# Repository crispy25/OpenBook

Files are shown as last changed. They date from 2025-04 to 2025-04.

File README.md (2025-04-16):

# OpenBook - TSC Project
### Author: Popescu Cristian-Emanuel 332CA

## Diagram

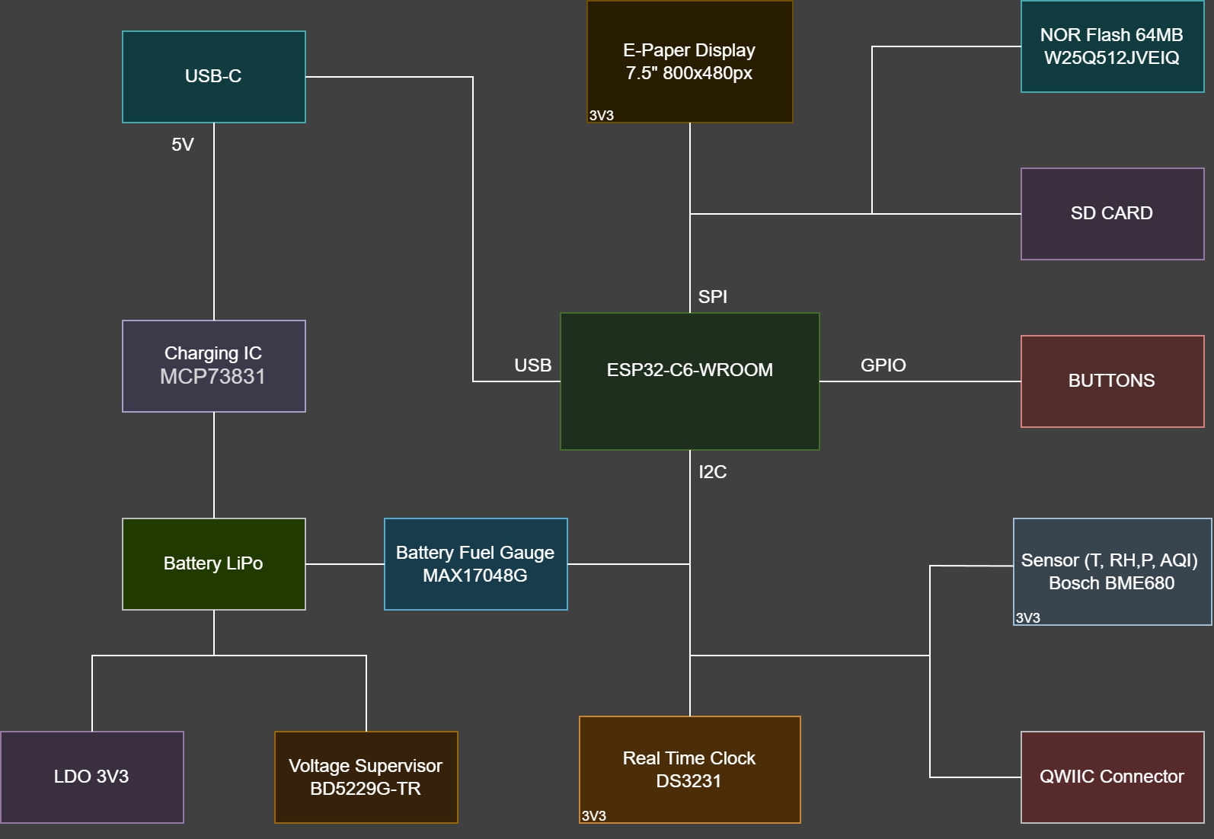
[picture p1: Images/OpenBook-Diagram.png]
OpenBook Diagram


## Hardware functionality

+ ESP32-C6 MCU
    - Manages all peripherals, including the display, sensors, buttons, and USB-C interface.
    - Interfaces: SPI, I2C, USB, UART, Wi-Fi

+ Power Supply - CELLEVIA BATTERIES LP584174
    - The 1800mAh Polymer Lithium-Ion battery is connected to the charging IC.
    - A single LDO generates the required single 3.3V power rail for the entire board, powering the ESP32, sensors and other components.

+ Battery management - MAX17048G+T10
    - The battery management module is using the I2C interface to communicate with the battery fuel gauge IC.
    - The charging IC is controlled via GPIO pins.

+ Display Interface - Waveshare WSH-13187 7.5" e-Paper display 
    - The 800x480 resolution display is connected to the ESP32-C6 via a 4-wire SPI interface.
    - Dedicated CS, DC, RST, and BUSY pins are used for control.

+ Sensor - Bosch BME680
    - Measures temperature, humidity, pressure and air quality.
    - The BME680 sensor is connected to the ESP32-C6 via an I2C bus.
    - Pull-up resistors are used on the I2C lines.

+ RTC - DS3231
    - Real Time Clock with supercapacitor back-up.
    - Connected via I2C interface.

+ User Interface
    - The three tactile buttons are connected to GPIO pins on the ESP32-C6.
    - Hardware debouncing circuitry is implemented using RC filters.
    - The RESET button restarts the device, typically used to recover from unresponsive states or system errors.
    - The BOOT button allows the user to start up the device.
    - The CHANGE button lets the user scroll or cycle through menus and book selections.

+ External NOR Flash 64MB - W25Q512JVEIQ
    - Non-Volatile flash memory that provides a storage solution.
    - Interface: SPI

+ USB-C Interface
    - The USB-C connector is connected to the ESP32-C6's USB interface.
    - A dedicated ESD protection IC is used on the data and power lines.
    - Proper termination resistors are used for USB-C implementation.

+ SD Memory Card Connector - Attend Tech 112A-TAAR-R03
    - Interface: SPI

+ Qwiic / Stemma QT
    - Plug-and-play I2C connection system for easy expansion of peripheral modules.

## Power management and consumption

| Mode | ESP32  | EPD  | BME680 | DS3231  | MAX17048 | SD Card | Total Current | Runtime |
|---|---|---|---|---|---|---|---|:---:|
| Active | 100mA  | 30mA | 2mA | 0.2mA | 0.05mA | 80mA | ~212 mA | ~8.5 hours |
| Idle | 50mA | 1µA  | 150µA | 0.2mA | 0.05mA | 2mA | ~52.4 mA | ~1.4 days |
| Deep Sleep | 0.15mA | 1µA  | 0.00015mA | 0.003mA | 0.001mA  | 0.1mA | ~0.255 mA | ~9.7 months |

## ESP32-C6 Pin description

+ EN -> Resets the MCU
+ IO0 - INT_RTC -> Used to receive interrupts signals from RTC, allowing for two major functionalities: Alarm and Square Wave Output
+ IO1 - 32KHz -> Used for a stable clock signal of 32.768 kHz generated by the RTC
+ IO2 – MISO -> Master In Slave Out Signal, used in the SPI communication with the SD Card
+ IO3 - EPD_BUSY -> Indicates display driver status
+ IO4 – SS_SD -> Chip select for SPI communication with SD Card
+ IO5 – EPD_DC -> Display serial communication Command/Data input
+ IO6 – SCK -> Clock signal for I2C communication
+ IO7 – MOSI -> Master Out Slave In Signal, used to send data to display and SD Card
+ IO8 - GPIO8 - Controls MCU boot mode
+ IO9 - IO/BOOT -> Used to detect BOOT button press
+ NC -> Not connected
+ 3V3 -> Used to power the MCU and the other components
+ IO10 - EPD_CS -> Chip select for SPI serial communication with the display
+ IO11 - FLASH_CS -> Chip select for SPI communication with the flash
+ IO12 - USB_D- -> Used in USB differential communication
+ IO13 - USB_D+ -> Used in USB differential communication
+ IO15 - IO/CHANGE -> Used to detect CHANGE button press
+ TXD0/GPIO16 - TX -> Sends data to another device via UART
+ RXD0/GPIO17 - RX -> Receives data from another device via UART
+ IO18 - RTC_RST -> Resets the RTC
+ IO19 - I2C_PW -> Power source for I2C components
+ IO20 - EPD_3V3_C -> Display IO voltage supply
+ IO21 - SDA -> Used to send and receive data in the I2C communication with the sensor, RTC module and Battery Fuel Gauge
+ IO22 - SCL -> Clock signal for I2C communication
+ IO23 - EPD_RST -> Global reset signal for the display
+ GND -> Shared Voltage Reference

## Bill of Materials:
| | | | | |
| --- | --- | --- | --- | --- |
| Parts | Value | Qty | CHECK_PRICES | DATASHEET |
| CHG_LED | | 1 | [https://ro.mouser.com/ProductDetail/ams-OSRAM/KO-EELP41.22-Q1S2-25-A8J8-020-R18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](https://ro.mouser.com/ProductDetail/ams-OSRAM/KO-EELP41.22-Q1S2-25-A8J8-020-R18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) | [https://www.farnell.com/datasheets/4386964.pdf](https://www.farnell.com/datasheets/4386964.pdf) |
| SJ1 | | 1 | [https://ro.mouser.com/ProductDetail/ROHM-Semiconductor/PMR01ZZPJ000?qs=jQ44l%2F%2F3jsmEdW2XxNXnVw%3D%3D](https://ro.mouser.com/ProductDetail/ROHM-Semiconductor/PMR01ZZPJ000?qs=jQ44l%2F%2F3jsmEdW2XxNXnVw%3D%3D) | [https://fscdn.rohm.com/en/products/databook/datasheet/passive/resistor/chip_resistor/pmr_series-e.pdf](https://fscdn.rohm.com/en/products/databook/datasheet/passive/resistor/chip_resistor/pmr_series-e.pdf) |
| C7 | 10uF | 1 | [https://ro.mouser.com/ProductDetail/KYOCERA-AVX/CM05X5R106M10AH?qs=MyNHzdoqoQKSCgSEDR5Ylg%3D%3D](https://ro.mouser.com/ProductDetail/KYOCERA-AVX/CM05X5R106M10AH?qs=MyNHzdoqoQKSCgSEDR5Ylg%3D%3D) | [https://ro.mouser.com/datasheet/2/40/CM_Series_e-2835982.pdf](https://ro.mouser.com/datasheet/2/40/CM_Series_e-2835982.pdf) |
| EPD_C5 | 0.1uF/50V | 1 | [04025C104JAT2A KYOCERA AVX \| Mouser Romania](https://ro.mouser.com/ProductDetail/KYOCERA-AVX/04025C104JAT2A?qs=yqaQSyyJnNjAUYBPnTRwrw%3D%3D) | [https://ro.mouser.com/datasheet/2/40/AutoMLCC-2952695.pdf](https://ro.mouser.com/datasheet/2/40/AutoMLCC-2952695.pdf) |
| R3 | 0.47 | 1 | [https://ro.mouser.com/ProductDetail/Vishay-Dale/RCWE0402R470FKEA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](https://ro.mouser.com/ProductDetail/Vishay-Dale/RCWE0402R470FKEA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) | [rcwe.pdf](https://www.vishay.com/docs/20019/rcwe.pdf) |
| R1_PWRUSB | 100K | 1 | [MCS0402MD1003BE000 Vishay / Beyschlag \| Mouser Romania](https://ro.mouser.com/ProductDetail/Vishay-Beyschlag/MCS0402MD1003BE000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) | [mcs0402at-mct0603at-mcu0805at-mca1206at.pdf](https://www.vishay.com/docs/28952/mcs0402at-mct0603at-mcu0805at-mca1206at.pdf) |
| C1, C2, C4_USB, C6, C8, C9, C10, C_DELAY | 100nF | 8 | [0402YC104MAT2A KYOCERA AVX \| Mouser Romania](https://ro.mouser.com/ProductDetail/KYOCERA-AVX/0402YC104MAT2A?qs=O2%2FeDh0sX9yiCaLwpXy1bw%3D%3D) | [https://ro.mouser.com/datasheet/2/40/KGM_X7R-3223212.pdf](https://ro.mouser.com/datasheet/2/40/KGM_X7R-3223212.pdf) |
| C3 | 100uF | 1 | [F910J107MBAAJ6 KYOCERA AVX \| Mouser Romania](https://ro.mouser.com/ProductDetail/KYOCERA-AVX/F910J107MBAAJ6?qs=PqoDHHvF649LraCA%2FjeGXg%3D%3D) | https://ro.mouser.com/datasheet/2/40/F91_AJ6-3162641.pdf |
| R1, R1_PINH, R1_PINH1, R2-PINH, R2-PINH1, R4, R5, R6, R7, R8, R9, R10, R_BOOT, R_CHANGE, R_CL1, R_RESET | 10K | 16  | [CRCW040210K0FKEDC Vishay / Dale \| Mouser Romania](https://ro.mouser.com/ProductDetail/Vishay-Dale/CRCW040210K0FKEDC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) | [crcwce3.pdf](https://www.vishay.com/docs/28773/crcwce3.pdf) |
| J4 | 112A-TAAR-R03_ATTEND | 1 | [https://store.comet.srl.ro/Catalogue/Product/43497/](https://store.comet.srl.ro/Catalogue/Product/43497/) | [https://www.attend.com.tw/data/download/file/112A-TAAR-R03_Spec.pdf](https://www.attend.com.tw/data/download/file/112A-TAAR-R03_Spec.pdf) |
| R_CAPACITOR | 15 | 1 | [https://ro.mouser.com/ProductDetail/Vishay-Dale/CRCW040215R0FKEDC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](https://ro.mouser.com/ProductDetail/Vishay-Dale/CRCW040215R0FKEDC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) | [crcwce3.pdf](https://www.vishay.com/docs/28773/crcwce3.pdf) |
| C5 | 1uF | 1 | [0402YC104MAT2A KYOCERA AVX \| Mouser Romania](https://ro.mouser.com/ProductDetail/KYOCERA-AVX/0402YC104MAT2A?qs=O2%2FeDh0sX9yiCaLwpXy1bw%3D%3D) | [https://ro.mouser.com/datasheet/2/40/KGM_X7R-3223212.pdf](https://ro.mouser.com/datasheet/2/40/KGM_X7R-3223212.pdf) |
| EPD_C1, EPD_C2, EPD_C6, EPD_C7, EPD_C8, EPD_C9, EPD_C10, EPD_C11, EPD_C12 | 1uF/50V | 9 | [GRM155R61H105KE05D Murata Electronics \| Mouser Romania](https://ro.mouser.com/ProductDetail/Murata-Electronics/GRM155R61H105KE05D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) | [GRM155R61H105KE05_01A-1983895.pdf](https://ro.mouser.com/datasheet/2/281/1/GRM155R61H105KE05_01A-1983895.pdf) |
| R2 | 2.2 | 1 | [CRCW04022R20JNEDHP Vishay / Dale \| Mouser Romania](https://ro.mouser.com/ProductDetail/Vishay-Dale/CRCW04022R20JNEDHP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) | [https://www.vishay.com/docs/20043/crcwhpe3.pdf](https://www.vishay.com/docs/20043/crcwhpe3.pdf) |
| R1_BAT | 200 | 1 | [CRCW0402200RJNEDHP Vishay / Dale \| Mouser Romania](https://ro.mouser.com/ProductDetail/Vishay-Dale/CRCW0402200RJNEDHP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) | [crcwhpe3.pdf](https://www.vishay.com/docs/20043/crcwhpe3.pdf) |
| Q1, Q2 | 20V/4.2A/52mO/1.4W | 2 | [https://ro.mouser.com/ProductDetail/Diodes-Incorporated/DMG2305UX-7?qs=L1DZKBg7t5F%2FNBHrjfxC%252Bg%3D%3D](https://ro.mouser.com/ProductDetail/Diodes-Incorporated/DMG2305UX-7?qs=L1DZKBg7t5F%2FNBHrjfxC%252Bg%3D%3D) | [DMG2305UX](https://www.diodes.com/assets/Datasheets/DMG2305UX.pdf) |
| R2_BAT | 2K | 1 | [MCS0402PD2001DE500 Vishay / Beyschlag \| Mouser Romania](https://ro.mouser.com/ProductDetail/Vishay-Beyschlag/MCS0402PD2001DE500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) | [https://www.vishay.com/docs/28916/mcxhp.pdf](https://www.vishay.com/docs/28916/mcxhp.pdf) |
| C1_BAT, C1_BAT1, C1_BAT2, C2_BAT, C5_USB | 4.7uF | 5 | [CM05X5R475M25AH KYOCERA AVX \| Mouser Romania](https://ro.mouser.com/ProductDetail/KYOCERA-AVX/CM05X5R475M25AH?qs=MyNHzdoqoQJvFdZaEuclBg%3D%3D) | https://ro.mouser.com/datasheet/2/40/CM_Series_e-2835982.pdf |
| C4 | 4.7uF/25V | 1 | [CM05X5R475M25AH KYOCERA AVX \| Mouser Romania](https://ro.mouser.com/ProductDetail/KYOCERA-AVX/CM05X5R475M25AH?qs=MyNHzdoqoQJvFdZaEuclBg%3D%3D) | https://ro.mouser.com/datasheet/2/40/CM_Series_e-2835982.pdf |
| R2-USB, R2-USB1 | 5k1 | 2 | [https://ro.mouser.com/ProductDetail/Vishay-Beyschlag/MCS04020C5101FE000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](https://ro.mouser.com/ProductDetail/Vishay-Beyschlag/MCS04020C5101FE000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) | [mcx0x0xpro.pdf](https://www.vishay.com/docs/28705/mcx0x0xpro.pdf) |
| L1 | 68uH | 1 | [https://ro.mouser.com/ProductDetail/Wurth-Elektronik/744043680?qs=PGXP4M47uW6VkZq%252BkzjrHA%3D%3D](https://ro.mouser.com/ProductDetail/Wurth-Elektronik/744043680?qs=PGXP4M47uW6VkZq%252BkzjrHA%3D%3D) | [744043680 Datasheet WE-TPC SMT Shielded Tiny Power Inductor](https://www.we-online.com/components/products/datasheet/744043680.pdf) |
| IC1 | BD5229G-TR | 1 | [https://ro.mouser.com/ProductDetail/ROHM-Semiconductor/BD5229G-TR?qs=4kLU8WoGk0vvnhrrYwdszw%3D%3D](https://ro.mouser.com/ProductDetail/ROHM-Semiconductor/BD5229G-TR?qs=4kLU8WoGk0vvnhrrYwdszw%3D%3D) | [BD52xx Series / BD53xx Series : Power Management](https://fscdn.rohm.com/en/products/databook/datasheet/ic/power/voltage_detector/bd52xxg-e.pdf) |
| BOOT_BUTTON, CHANGE_BUTTON, RESET_BUTTON | BUTTON_CUSYOMV1 | 3 | [https://ro.mouser.com/ProductDetail/Panasonic/EVQ-P7L01P?qs=rJ%252BziJWpyszWhhNszc02jQ%3D%3D](https://ro.mouser.com/ProductDetail/Panasonic/EVQ-P7L01P?qs=rJ%252BziJWpyszWhhNszc02jQ%3D%3D) | [https://api.pim.na.industrial.panasonic.com/file_stream/main/fileversion/245500](https://api.pim.na.industrial.panasonic.com/file_stream/main/fileversion/245500) |
| C10_SUPERCAP | CPH3225A | 1 | [https://ro.mouser.com/ProductDetail/Seiko-Semiconductors/CPH3225A?qs=3etwrb1wR%252BhUOph6lAO7eg%3D%3D](https://ro.mouser.com/ProductDetail/Seiko-Semiconductors/CPH3225A?qs=3etwrb1wR%252BhUOph6lAO7eg%3D%3D) | [https://ro.mouser.com/datasheet/2/360/Seiko_Instruments_MicroBattery_E_20230330_2024Jan_-3561061.pdf](https://ro.mouser.com/datasheet/2/360/Seiko_Instruments_MicroBattery_E_20230330_2024Jan_-3561061.pdf) |
| U3 | DS3231SN# | 1 | [https://ro.mouser.com/ProductDetail/Analog-Devices-Maxim-Integrated/DS3231SN?qs=1eQvB6Dk1vhUlr8%2FOrV0Fw%3D%3D](https://ro.mouser.com/ProductDetail/Analog-Devices-Maxim-Integrated/DS3231SN?qs=1eQvB6Dk1vhUlr8%2FOrV0Fw%3D%3D) | [DS3231-3421123.pdf](https://ro.mouser.com/datasheet/2/609/DS3231-3421123.pdf) |
| U2 | ESP32-C6-WROOM-1-N8 | 1 | [https://ro.mouser.com/ProductDetail/Espressif-Systems/ESP32-C6-WROOM-1-N8?qs=8Wlm6%252BaMh8ST02Gmwp74cw%3D%3D](https://ro.mouser.com/ProductDetail/Espressif-Systems/ESP32-C6-WROOM-1-N8?qs=8Wlm6%252BaMh8ST02Gmwp74cw%3D%3D) | [Espressif_ESP32_C6_WROOM_1__Datasheet_V0_1_PRELIMI-3239987.pdf](https://ro.mouser.com/datasheet/2/891/Espressif_ESP32_C6_WROOM_1__Datasheet_V0_1_PRELIMI-3239987.pdf) |
| PFMF.050.1 | ESP32C6_VARISTORCN1812 | 1 | [https://ro.mouser.com/ProductDetail/Bourns/BVR1812-04R?qs=mELouGlnn3dev%2FRLzuGBiQ%3D%3D](https://ro.mouser.com/ProductDetail/Bourns/BVR1812-04R?qs=mELouGlnn3dev%2FRLzuGBiQ%3D%3D) | [BVR1812 SMD Series Low Voltage Varistors](https://ro.mouser.com/datasheet/2/54/Bourns_12_20_2023_BVR1812_Datasheet-3386163.pdf) |
| D2, D7 | ESP32_WROVER_AVX---SD0805S020S1R0_AVX_SD0805S020S1R0_0_0AVX_SD0805S020S1R0_0_0 | 2 | [SD0805S020S1R0 KYOCERA AVX \| Mouser Romania](https://ro.mouser.com/ProductDetail/KYOCERA-AVX/SD0805S020S1R0?qs=jCA%252BPfw4LHbpkAoSnwrdjw%3D%3D) | [https://ro.mouser.com/datasheet/2/40/schottky-3165252.pdf](https://ro.mouser.com/datasheet/2/40/schottky-3165252.pdf) |
| SENSOR2 | ESP32_WROVER_BME680_BME680 | 1 | [https://ro.mouser.com/ProductDetail/Bosch-Sensortec/BME680?qs=v271MhAjFHjo0yA%2FC4OnDQ%3D%3D](https://ro.mouser.com/ProductDetail/Bosch-Sensortec/BME680?qs=v271MhAjFHjo0yA%2FC4OnDQ%3D%3D) | [https://ro.mouser.com/datasheet/2/783/BST_BME680_DS001-1509608.pdf](https://ro.mouser.com/datasheet/2/783/BST_BME680_DS001-1509608.pdf) |
| MCP73831 | ESP32_WROVER_SPARKFUN-IC-POWER_MCP73831 | 1 | [https://ro.mouser.com/ProductDetail/Microchip-Technology/MCP73831T-2ACI-OT?qs=yUQqVecv4qvbBQBGbHx0Mw%3D%3D](https://ro.mouser.com/ProductDetail/Microchip-Technology/MCP73831T-2ACI-OT?qs=yUQqVecv4qvbBQBGbHx0Mw%3D%3D) | [MCP73831/MCP73832 Data Sheet](https://ro.mouser.com/datasheet/2/268/MCP73831_Family_Data_Sheet_DS20001984H-3441711.pdf) |
| J1 | FH34SRJ-24S-0.5SH_99_ | 1 | [FH34SRJ-24S-0.5SH(99) Hirose Connector \| Mouser Romania](https://ro.mouser.com/ProductDetail/Hirose-Connector/FH34SRJ-24S-0.5SH99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) | [https://ro.mouser.com/datasheet/2/185/FH34SRJ_24S_0_5SH_99__CL0580_1255_6_99_2DDrawing_0-1615044.pdf](https://ro.mouser.com/datasheet/2/185/FH34SRJ_24S_0_5SH_99__CL0580_1255_6_99_2DDrawing_0-1615044.pdf) |
| U4 | MAX17048G+T10 | 1 | [MAX17048G+T10 Analog Devices / Maxim Integrated \| Mouser Romania](https://ro.mouser.com/ProductDetail/Analog-Devices-Maxim-Integrated/MAX17048G%2bT10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) | [MAX17048_MAX17049-3469099.pdf](https://ro.mouser.com/datasheet/2/609/MAX17048_MAX17049-3469099.pdf) |
| D3, D4, D5 | MBR0530 | 3 | [https://ro.mouser.com/ProductDetail/onsemi/MBR0530T1G?qs=3JMERSakeboS%2FFOxJUMWeg%3D%3D](https://ro.mouser.com/ProductDetail/onsemi/MBR0530T1G?qs=3JMERSakeboS%2FFOxJUMWeg%3D%3D) | [MBR0530T1 - Surface Mount Schottky Power Rectifier](https://www.onsemi.com/download/data-sheet/pdf/mbr0530t1-d.pdf) |
| D6, D8, D9, D10, D11, D12 | PGB1010603MR | 6 | [PGB1010603MR Littelfuse \| Mouser Romania](https://ro.mouser.com/ProductDetail/Littelfuse/PGB1010603MR?qs=gu7KAQ731URLg4GSnNNN7Q%3D%3D) | [pulseguard-esd-suppressors-pgb1-datasheet](https://www.littelfuse.com/assetdocs/pulseguard-esd-suppressors-pgb1-datasheet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) |
| J3 | QWIIC_RIGHT_ANGLE | 1 | [https://ro.mouser.com/ProductDetail/SparkFun/PRT-14417?qs=wd5RIQLrsJhgdz%2FpmZ%2F3GQ%3D%3D](https://ro.mouser.com/ProductDetail/SparkFun/PRT-14417?qs=wd5RIQLrsJhgdz%2FpmZ%2F3GQ%3D%3D) | [eSH.doc](https://ro.mouser.com/datasheet/2/813/Qwiic_Connector_Datasheet-1223982.pdf) |
| J2 | SAMACSYS_PARTS_USB4110-GF-A | 1 | [USB4110-GF-A GCT \| Mouser Romania](https://ro.mouser.com/ProductDetail/GCT/USB4110-GF-A?qs=KUoIvG%2F9IlYiZvIXQjyJeA%3D%3D) | [https://ro.mouser.com/datasheet/2/837/GCT_USB4110_Product_Drawing___20k_cycles-3455479.pdf](https://ro.mouser.com/datasheet/2/837/GCT_USB4110_Product_Drawing___20k_cycles-3455479.pdf) |
| Q3 | SI1308EDL-T1-GE3 | 1 | [SI1308EDL-T1-GE3 Vishay Semiconductors \| Mouser Romania](https://ro.mouser.com/ProductDetail/Vishay-Semiconductors/SI1308EDL-T1-GE3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) | [si1308edl.pdf](https://www.vishay.com/docs/63399/si1308edl.pdf) |
| TP1, TP2, TP3, TP4, TP5, TP6, TP7, TP8, TP9, TP10, TP11, TP12, TP13, TP14, TP15, TP16, TP17 | TPTP20R | 17  | \- | \- |
| D1 | USBLC6-2SC6Y | 1 | [https://ro.mouser.com/ProductDetail/STMicroelectronics/USBLC6-2SC6Y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](https://ro.mouser.com/ProductDetail/STMicroelectronics/USBLC6-2SC6Y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) | https://ro.mouser.com/datasheet/2/389/usblc6_2sc6y-1852505.pdf |
| U1 | W25Q512JVEIQ | 1 | [https://ro.mouser.com/ProductDetail/Winbond/W25Q512JVEIQ?qs=l7cgNqFNU1jw6svr3at6tA%3D%3D](https://ro.mouser.com/ProductDetail/Winbond/W25Q512JVEIQ?qs=l7cgNqFNU1jw6svr3at6tA%3D%3D) | [Winbond_W25Q512JV_Datasheet-3240039.pdf](https://ro.mouser.com/datasheet/2/949/Winbond_W25Q512JV_Datasheet-3240039.pdf) |
| IC4 | XC6220A331MR-G | 1 | [https://ro.mouser.com/ProductDetail/Torex-Semiconductor/XC6220A331MR-G?qs=AsjdqWjXhJ8ZSWznL1J0gg%3D%3D](https://ro.mouser.com/ProductDetail/Torex-Semiconductor/XC6220A331MR-G?qs=AsjdqWjXhJ8ZSWznL1J0gg%3D%3D) | [xc6220-3371556.pdf](https://ro.mouser.com/datasheet/2/760/xc6220-3371556.pdf) |

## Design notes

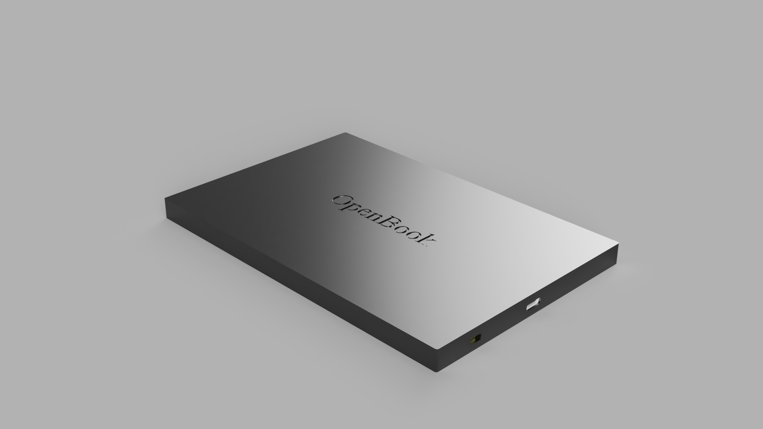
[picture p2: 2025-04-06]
Images/OpenBook_Back.png

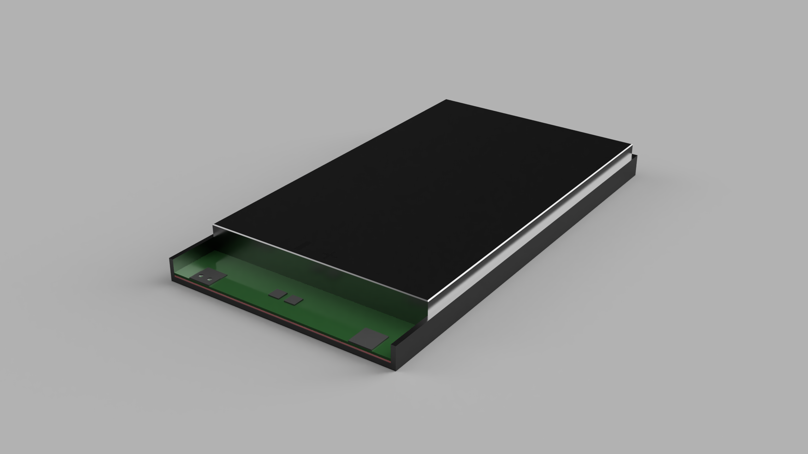
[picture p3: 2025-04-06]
Images/Battery.png

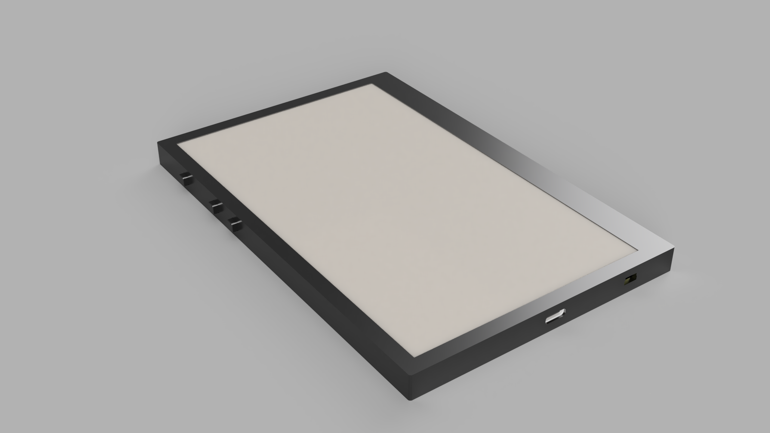
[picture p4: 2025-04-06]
Images/OpenBook_Front.png

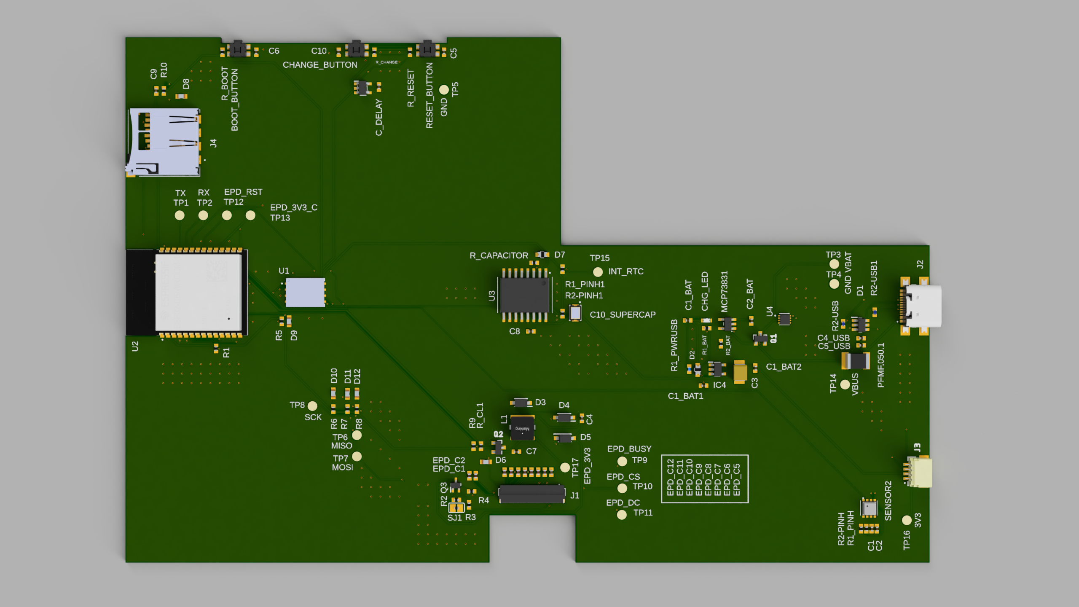
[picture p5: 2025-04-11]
Images/PCB_Top.png

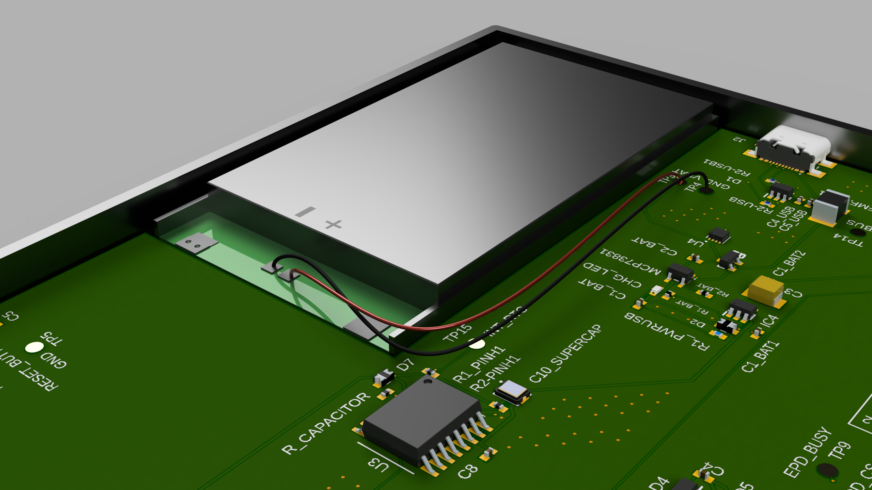
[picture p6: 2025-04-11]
Images/Battery_Inside_PCB.png

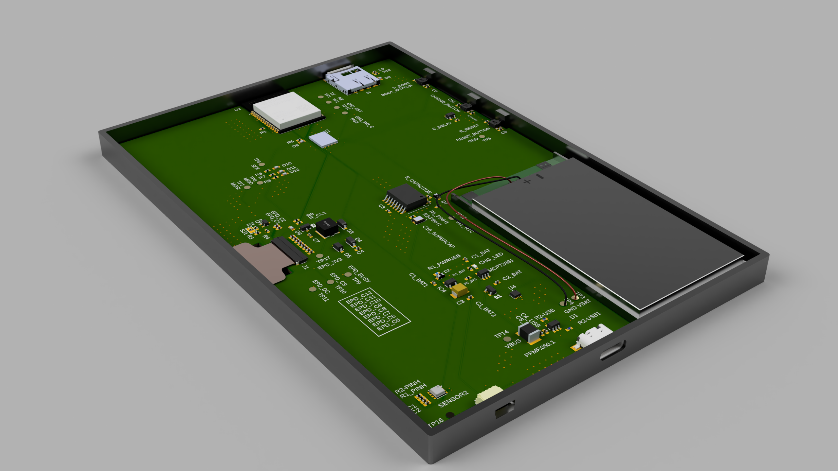
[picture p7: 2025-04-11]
Images/OpenBook_Opened.png

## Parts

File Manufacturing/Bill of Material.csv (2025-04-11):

Qty | Value | Device | Package | Parts | Description | ARROW_PART_NUMBER | ARROW_PRICE-STOCK | AVAILABILITY | CENTROID_NOT_SPECIFIED | CHECK_PRICES | COPYRIGHT | DATASHEET | DESCRIPTION | DIGIKEY_DESCRIPTION | DIGIKEY_PART_NUMBER | HEIGHT | LEAD_FREE | MANUFACTURER_NAME | MANUFACTURER_PART_NUMBER | MF | MFR_NAME | MOUSER_PART_NUMBER | MOUSER_PRICE-STOCK | MOUSER_TESTING_PART_NUMBER | MOUSER_TESTING_PRICE-STOCK | MP | MPN | PACKAGE | POPULARITY | PREFIX | PRICE | PROD_ID | PURCHASE-URL | ROHS | SNAPEDA_LINK | SPICEMODEL | SPICEPREFIX | TEMPERATURE_RANGE_HIGH | TEMPERATURE_RANGE_LOW | TP_SIGNAL_NAME | VALUE
1 |  | ADAFRUIT_LEDCHIP-LED0603 | ADAFRUIT_CHIP-LED0603 | CHG_LED | LED
1 |  | SJ | SJ | SJ1 | SMD solder JUMPER |  |  |  |  |  |  |  |  |  |  |  |  |  |  |  |  |  |  |  |  |  |  |  | 3
1 | 0.1uF/50V | ESP32_WROVER_EAGLE-LTSPICE_CC0402 | ESP32_WROVER_EAGLE-LTSPICE_C0402 | EPD_C5 | CAPACITOR, European symbol |  |  |  |  |  |  |  |  |  |  |  |  |  |  |  |  |  |  |  |  |  |  |  |  |  |  |  |  |  |  | NONE | C
1 | 0.47 | ESP32_WROVER_EAGLE-LTSPICE_RR0402 | ESP32_WROVER_EAGLE-LTSPICE_R0402 | R3 | RESISTOR, European symbol |  |  |  |  |  |  |  |  |  |  |  |  |  |  |  |  |  |  |  |  |  |  |  |  |  |  |  |  |  |  | NONE | R
1 | 100K | ESP32_WROVER_EAGLE-LTSPICE_RR0402-MCS-100K | ESP32_WROVER_EAGLE-LTSPICE_R0402 | R1_PWRUSB | RESISTOR, European symbol
8 | 100nF | ESP32_WROVER_EAGLE-LTSPICE_CC0402 | ESP32_WROVER_EAGLE-LTSPICE_C0402 | C1, C2, C4_USB, C6, C8, C9, C10, C_DELAY | CAPACITOR, European symbol |  |  |  |  |  |  |  |  |  |  |  |  |  |  |  |  |  |  |  |  |  |  |  |  |  |  |  |  |  |  | NONE | C
1 | 100uF | RCL_CPOL-EUCT3528 | RCL_CT3528 | C3 | POLARIZED CAPACITOR, European symbol |  |  |  |  |  |  |  |  |  |  |  |  |  |  |  |  |  |  |  |  |  |  |  | 0 |  |  |  |  |  |  |  | C
16 | 10K | ESP32_WROVER_EAGLE-LTSPICE_RR0402 | ESP32_WROVER_EAGLE-LTSPICE_R0402 | R1, R1_PINH, R1_PINH1, R2-PINH, R2-PINH1, R4, R5, R6, R7, R8, R9, R10, R_BOOT, R_CHANGE, R_CL1, R_RESET | RESISTOR, European symbol |  |  |  |  |  |  |  |  |  |  |  |  |  |  |  |  |  |  |  |  |  |  |  |  |  |  |  |  |  |  | NONE | R
1 | 10uF | ESP32_WROVER_EAGLE-LTSPICE_CC0402 | ESP32_WROVER_EAGLE-LTSPICE_C0402 | C7 | CAPACITOR, European symbol |  |  |  |  |  |  |  |  |  |  |  |  |  |  |  |  |  |  |  |  |  |  |  |  |  |  |  |  |  |  | NONE | C
1 | 112A-TAAR-R03_ATTEND | 112A-TAAR-R03_ATTEND | 112ATAARR03ATTEND | J4 | Micro SD Card Socket, Push-Push Type, Top Mount, SMT, H=1.83mm, 10u |  |  |  |  |  |  |  | Micro SD Card Socket | Push-Push Type | Top Mount | SMT | H=1.83mm | 10u |  |  | 1.9mm |  | ATTEND | 112A-TAAR-R03 ATTEND
1 | 15 | ESP32_WROVER_EAGLE-LTSPICE_RR0402 | ESP32_WROVER_EAGLE-LTSPICE_R0402 | R_CAPACITOR | RESISTOR, European symbol |  |  |  |  |  |  |  |  |  |  |  |  |  |  |  |  |  |  |  |  |  |  |  |  |  |  |  |  |  |  | NONE | R
1 | 1uF | ESP32_WROVER_EAGLE-LTSPICE_CC0402 | ESP32_WROVER_EAGLE-LTSPICE_C0402 | C5 | CAPACITOR, European symbol |  |  |  |  |  |  |  |  |  |  |  |  |  |  |  |  |  |  |  |  |  |  |  |  |  |  |  |  |  |  | NONE | C
9 | 1uF/50V | ESP32_WROVER_EAGLE-LTSPICE_CC0402-1UF/50V | ESP32_WROVER_EAGLE-LTSPICE_C0402 | EPD_C1, EPD_C2, EPD_C6, EPD_C7, EPD_C8, EPD_C9, EPD_C10, EPD_C11, EPD_C12 | CAPACITOR, European symbol
1 | 2.2 | ESP32_WROVER_EAGLE-LTSPICE_RR0402 | ESP32_WROVER_EAGLE-LTSPICE_R0402 | R2 | RESISTOR, European symbol |  |  |  |  |  |  |  |  |  |  |  |  |  |  |  |  |  |  |  |  |  |  |  |  |  |  |  |  |  |  | NONE | R
1 | 200 | ESP32_WROVER_EAGLE-LTSPICE_RR0402-200 | ESP32_WROVER_EAGLE-LTSPICE_R0402 | R1_BAT | RESISTOR, European symbol
2 | 20V/4.2A/52mO/1.4W | ESP32_WROVER_SPARKFUN-DISCRETESEMI_MOSFET_PCH-DMG2305UX-7 | ESP32_WROVER_SPARKFUN-DISCRETESEMI_SOT23-3 | Q1, Q2 | P-channel MOSFETs |  |  |  |  |  |  |  |  |  |  |  |  |  |  |  |  |  |  |  |  |  |  |  |  |  |  | TRAN-14388 |  |  |  |  |  |  |  |  | 20V/4.2A/52mO/1.4W
1 | 2K | ESP32_WROVER_EAGLE-LTSPICE_RR0402 | ESP32_WROVER_EAGLE-LTSPICE_R0402 | R2_BAT | RESISTOR, European symbol |  |  |  |  |  |  |  |  |  |  |  |  |  |  |  |  |  |  |  |  |  |  |  |  |  |  |  |  |  |  | NONE | R
5 | 4.7uF | ESP32_WROVER_EAGLE-LTSPICE_CC0402-4.7UF | ESP32_WROVER_EAGLE-LTSPICE_C0402 | C1_BAT, C1_BAT1, C1_BAT2, C2_BAT, C5_USB | CAPACITOR, European symbol
1 | 4.7uF/25V | ESP32_WROVER_EAGLE-LTSPICE_CC0402-4.7UF | ESP32_WROVER_EAGLE-LTSPICE_C0402 | C4 | CAPACITOR, European symbol
2 | 5k1 | ESP32_WROVER_EAGLE-LTSPICE_RR0402-MCS | ESP32_WROVER_EAGLE-LTSPICE_R0402 | R2-USB, R2-USB1 | RESISTOR, European symbol
1 | 68uH | 744043680IND_4828-WE-TPC_WRE | IND_4828-WE-TPC_WRE | L1 |  |  |  |  |  |  | Copyright (C) 2024 Ultra Librarian. All rights reserved. |  |  |  |  |  |  |  | 744043680 |  | Wurth Electronics
1 | BD5229G-TR | BD5229G-TR | SOT95P280X125-5N | IC1 | Voltage Detector with Adjustable Delay Time: CMOS processes are utilized to develop high precision, low current consumption CMOS reset ICs that allow arbitrary setting of the delay time. The extensive lineup includes both Nch Open Drain and CMOS output types in a wide range of detection voltages (from 2.3V to 6.0V, in 0.1V steps), enabling selection of the ideal solution based on customer requirements. In addition, the entire series is of course both lead-free and RoHS-compliant. |  |  |  |  |  |  |  | Voltage Detector with Adjustable Delay Time: CMOS processes are utilized to develop high precision | low current consumption CMOS reset ICs that allow arbitrary setting of the delay time. The extensive lineup includes both Nch Open Drain and CMOS output types in a wide range of detection voltages (from 2.3V to 6.0V | in 0.1V steps) | enabling selection of the ideal solution based on customer requirements. In addition | the entire series is of course both lead-free and RoHS-compliant. |  |  | 1.25mm |  | ROHM Semiconductor | BD5229G-TR |  |  | 755-BD5229G-TR | https://www.mouser.co.uk/ProductDetail/ROHM-Semiconductor/BD5229G-TR?qs=4kLU8WoGk0vvnhrrYwdszw%3D%3D
3 | BUTTON_CUSYOMV1 | BUTTON_CUSYOMV1 | MYBUTTON | BOOT_BUTTON, CHANGE_BUTTON, RESET_BUTTON
1 | CPH3225A | CPH3225A | CAPCP3225X100N | C10_SUPERCAP | Cap 0.011F 3.3V 1210 Flat Check availability |  |  | Not in stock |  | https://www.snapeda.com/parts/CPH3225A/Seiko+Instruments/view-part/?ref=eda |  |  | 11 mF (EDLC) Supercapacitor 3.3 V 1210 (3225 Metric) - - |  |  |  |  |  |  | Seiko Instruments |  |  |  |  |  | CPH3225A |  | 1210 Seiko |  |  | None |  | https://www.snapeda.com/api/url_track_click_mouser/?unipart_id=562593&manufacturer=Seiko Instruments&part_name=CPH3225A&search_term=None |  | https://www.snapeda.com/parts/CPH3225A/Seiko+Instruments/view-part/?ref=snap
1 | DS3231SN# | DS3231SN# | SOIC127P1032X265-16N | U3 | Real Time Clock Serial 16-Pin SOIC W T/R Check availability |  |  | In Stock |  | https://www.snapeda.com/parts/DS3231SN%23/Analog+Devices/view-part/?ref=eda |  |  | Extremely Accurate I²C-Integrated RTC/TCXO/Crystal |  |  |  |  |  |  | Analog Devices |  |  |  |  |  | DS3231SN# |  | SOIC-16 Maxim |  |  | None |  | https://www.snapeda.com/api/url_track_click_mouser/?unipart_id=99048&manufacturer=Analog Devices&part_name=DS3231SN#&search_term=None |  | https://www.snapeda.com/parts/DS3231SN%23/Analog+Devices/view-part/?ref=snap
1 | ESP32-C6-WROOM-1-N8 | ESP32-C6-WROOM-1-N8 | XCVR_ESP32-C6-WROOM-1-N8 | U2 | Check availability |  |  | In Stock |  | https://www.snapeda.com/parts/ESP32-C6-WROOM-1-N8/Espressif+Systems/view-part/?ref=eda |  |  | Multiprotocol Modules ESP32-C6 module | Wi-Fi 6 in 2.4 GHz band | Bluetooth 5 | Zigbee 3.0 and Thread. ESP34-WROOM Compatible - ENGINEERING SAMPLE |  |  |  |  |  |  | Espressif Systems |  |  |  |  |  | ESP32-C6-WROOM-1-N8 |  | None |  |  | None |  |  |  | https://www.snapeda.com/parts/ESP32-C6-WROOM-1-N8/Espressif+Systems/view-part/?ref=snap
1 | ESP32C6_VARISTORCN1812 | ESP32C6_VARISTORCN1812 | ESP32C6_VARISTOR_CT/CN1812 | PFMF.050.1 | VARISTOR |  |  |  |  |  |  |  |  |  |  |  |  |  |  |  |  |  |  |  |  |  |  |  | 0
2 | ESP32_WROVER_AVX---SD0805S020S1R0_AVX_SD0805S020S1R0_0_0AVX_SD0805S020S1R0_0_0 | ESP32_WROVER_AVX---SD0805S020S1R0_AVX_SD0805S020S1R0_0_0AVX_SD0805S020S1R0_0_0 | ESP32_WROVER_AVX---SD0805S020S1R0_AVX_SD0805S020S1R0_0 | D2, D7 | Schottky Barrier Rectifier Diode |  |  |  | No |  |  | http://datasheets.avx.com/schottky.pdf |  | DIODE SCHOTTKY 20V 1A 0805 | 478-7800-1-ND |  | yes |  |  | AVX |  | 581-SD0805S020S1R0 |  |  |  |  |  | 0805 (2012 metric) |  | D |  |  |  | yes |  |  |  | +125°C | -55°C
1 | ESP32_WROVER_BME680_BME680 | ESP32_WROVER_BME680_BME680 | ESP32_WROVER_BME680_PSON80P300X300X100-8N | SENSOR2 | Integrated Environmental Unit |  |  | Unavailable |  |  |  |  | Integrated Environmental Unit |  |  |  |  |  |  | Bosch Sensortec |  |  |  |  |  | BME680 |  | LGA-8 Bosch Tools |  |  | None
1 | ESP32_WROVER_SPARKFUN-IC-POWER_MCP73831 | ESP32_WROVER_SPARKFUN-IC-POWER_MCP73831 | ESP32_WROVER_SPARKFUN-IC-POWER_SOT23-5 | MCP73831 | MCP73831T Li-Ion, Li-Pol Controller |  |  |  |  |  |  |  |  |  |  |  |  |  |  |  |  |  |  |  |  |  |  |  |  |  |  | IC-09995
1 | FH34SRJ-24S-0.5SH_99_ | FH34SRJ-24S-0.5SH_99_ | FH34SRJ24S05SH99 | J1 | (0.50mm) Surface Mount, Right Angle |  |  |  |  |  |  |  | 24 Position FFC | FPC Connector Contacts | (0.50mm) Surface Mount | Right Angle |  |  | 1.1mm |  | Hirose | FH34SRJ-24S-0.5SH(99) |  |  | 798-FH34SRJ24S05SH99 | https://www.mouser.co.uk/ProductDetail/Hirose-Connector/FH34SRJ-24S-0.5SH99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
1 | MAX17048G+T10 | MAX17048G+T10 | SON50P200X200X80-9N | U4 | Check availability |  |  | In Stock |  | https://www.snapeda.com/parts/MAX17048G+T10/Analog+Devices/view-part/?ref=eda |  |  | 3µA 1-Cell/2-Cell Fuel Gauge with ModelGauge |  |  |  |  |  |  | Analog Devices |  |  |  |  |  | MAX17048G+T10 |  | TDFN-8 Maxim |  |  | None |  | https://www.snapeda.com/api/url_track_click_mouser/?unipart_id=329239&manufacturer=Analog Devices&part_name=MAX17048G+T10&search_term=None |  | https://www.snapeda.com/parts/MAX17048G+T10/Analog+Devices/view-part/?ref=snap
3 | MBR0530 | MBR0530 | SOD3716X135N | D3, D4, D5 | ON SEMICONDUCTOR - MBR0530 - DIODE, SCHOTTKY, 0.5A, 30V, SOD-123 |  |  | In Stock |  | https://www.snapeda.com/parts/MBR0530/Onsemi/view-part/?ref=eda |  |  | Diode Schottky 30 V 500mA Surface Mount SOD-123 |  |  |  |  |  |  | ON Semiconductor |  |  |  |  |  | MBR0530 |  | SOD-123-2 ON Semiconductor |  |  | None |  | https://www.snapeda.com/api/url_track_click_mouser/?unipart_id=179458&manufacturer=ON Semiconductor&part_name=MBR0530&search_term=None |  | https://www.snapeda.com/parts/MBR0530/Onsemi/view-part/?ref=snap
6 | PGB1010603MR | PGB1010603MR | DIOC1608X36N | D6, D8, D9, D10, D11, D12 | Check availability |  |  | In Stock |  | https://www.snapeda.com/parts/PGB1010603MR/Littelfuse/view-part/?ref=eda |  |  | 150V (Typ) Clamp - Ipp Tvs Diode Surface Mount 0603 (1608 Metric) |  |  |  |  |  |  | Littelfuse Inc. |  |  |  |  |  | PGB1010603MR |  | 0603 Littelfuse Inc. |  |  | None |  | https://www.snapeda.com/api/url_track_click_mouser/?unipart_id=5659453&manufacturer=Littelfuse Inc.&part_name=PGB1010603MR&search_term=None |  | https://www.snapeda.com/parts/PGB1010603MR/Littelfuse/view-part/?ref=snap
1 | QWIIC_RIGHT_ANGLE | QWIIC_CONNECTORJS-1MM | JST04_1MM_RA | J3 | SparkFun I2C Standard Qwiic Connector |  |  |  |  |  |  |  |  |  |  |  |  |  |  |  |  |  |  |  |  |  |  |  |  |  |  | CONN-13694 |  |  |  |  |  |  |  |  | QWIIC_RIGHT_ANGLE
1 | SAMACSYS_PARTS_USB4110-GF-A | SAMACSYS_PARTS_USB4110-GF-A | SAMACSYS_PARTS_USB4110GFA | J2 | CONN USB 2.0 TYPE-C R/A SMT |  |  |  |  |  |  |  | CONN USB 2.0 TYPE-C R/A SMT |  |  | 3.26mm |  | GCT (GLOBAL CONNECTOR TECHNOLOGY) | USB4110-GF-A |  |  | 640-USB4110-GF-A | https://www.mouser.co.uk/ProductDetail/GCT/USB4110-GF-A?qs=KUoIvG%2F9IlYiZvIXQjyJeA%3D%3D
1 | SI1308EDL-T1-GE3 | SI1308EDL-T1-GE3 | SOT65P210X110-3N | Q3 | MOSFET N-Ch 30V 1.5A TrenchFET SC70 Vishay Si1308EDL-T1-GE3 N-channel MOSFET Transistor, 1.5 A, 30 V, 3-Pin SC-70 |  |  | In Stock |  | https://www.snapeda.com/parts/SI1308EDL-T1-GE3/Vishay+Siliconix/view-part/?ref=eda |  |  | Si1308EDL-T1-GE3 N-channel MOSFET Transistor | 1.5 A | 30 V | 3-Pin SC-70 | Siliconix / Vishay SI1308EDL-T1-GE3 |  |  |  |  |  |  | Vishay Siliconix |  |  |  |  |  | SI1308EDL-T1-GE3 |  | SOT-323 Vishay Semiconductor |  |  | None |  | https://www.snapeda.com/api/url_track_click_mouser/?unipart_id=274603&manufacturer=Vishay Siliconix&part_name=SI1308EDL-T1-GE3&search_term=None |  | https://www.snapeda.com/parts/SI1308EDL-T1-GE3/Vishay+Siliconix/view-part/?ref=snap
17 | TPTP20R | TPTP20R | TP20R | TP1, TP2, TP3, TP4, TP5, TP6, TP7, TP8, TP9, TP10, TP11, TP12, TP13, TP14, TP15, TP16, TP17 | Test pad |  |  |  |  |  |  |  |  |  |  |  |  |  |  |  |  |  |  |  |  |  |  |  | 2
1 | USBLC6-2SC6Y | USBLC6-2SC6Y | SOT95P280X145-6N | D1 | Low Cap. ESD Protection Auto SOT-23-6 STMicroelectronics USBLC6-2SC6Y, Dual Uni-Directional TVS Diode Array, 6-Pin SOT-23 |  |  | In Stock |  | https://www.snapeda.com/parts/USBLC6-2SC6Y/STMicroelectronics/view-part/?ref=eda |  |  | 17V Clamp 5A (8/20µs) Ipp Tvs Diode Surface Mount SOT-23-6 |  |  |  |  |  |  | STMicroelectronics |  |  |  |  |  | USBLC6-2SC6Y |  | SOT-23-6 STMicroelectronics |  |  | None |  |  |  | https://www.snapeda.com/parts/USBLC6-2SC6Y/STMicroelectronics/view-part/?ref=snap
1 | W25Q512JVEIQ | W25Q512JVEIQ | SON127P600X800X80-9N | U1 | Check availability |  |  | In Stock |  | https://www.snapeda.com/parts/W25Q512JVEIQ/Winbond+Electronics/view-part/?ref=eda |  |  | FLASH - NOR Memory IC 512Mb (64M x 8) SPI - Quad I/O 133 MHz 8-WSON (8x6) |  |  |  |  |  |  | Winbond Electronics |  |  |  |  |  | W25Q512JVEIQ |  | Package |  |  | None |  |  |  | https://www.snapeda.com/parts/W25Q512JVEIQ/Winbond+Electronics/view-part/?ref=snap
1 | XC6220A331MR-G | XC6220A331MR-G | SOT95P280X120-5N | IC4 | LDO Voltage Regulators |  |  |  |  |  |  |  | LDO Voltage Regulators |  |  | 1.2mm |  | Torex | XC6220A331MR-G |  |  | 865-XC6220A331MR-G | https://www.mouser.co.uk/ProductDetail/Torex-Semiconductor/XC6220A331MR-G?qs=AsjdqWjXhJ8ZSWznL1J0gg%3D%3D

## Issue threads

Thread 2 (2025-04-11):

90 Degree routes

mtusca, 2025-04-11:
The PCB contains 90 degree routes.

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

crispy25, 2025-04-14:
Fixed by 4ae2434 commit.

Closed 2025-04-14.

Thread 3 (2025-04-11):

PCB thickness

mtusca, 2025-04-11:
Should be 1.00mm, not 1.6mm

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

crispy25, 2025-04-14:
The layer stack property value is lost in the exported 2D PCB document, but the 3D model correctly shows a 1 mm thickness.

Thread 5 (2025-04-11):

Screen size issue

mtusca, 2025-04-11:
Diameter should be 3mm

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

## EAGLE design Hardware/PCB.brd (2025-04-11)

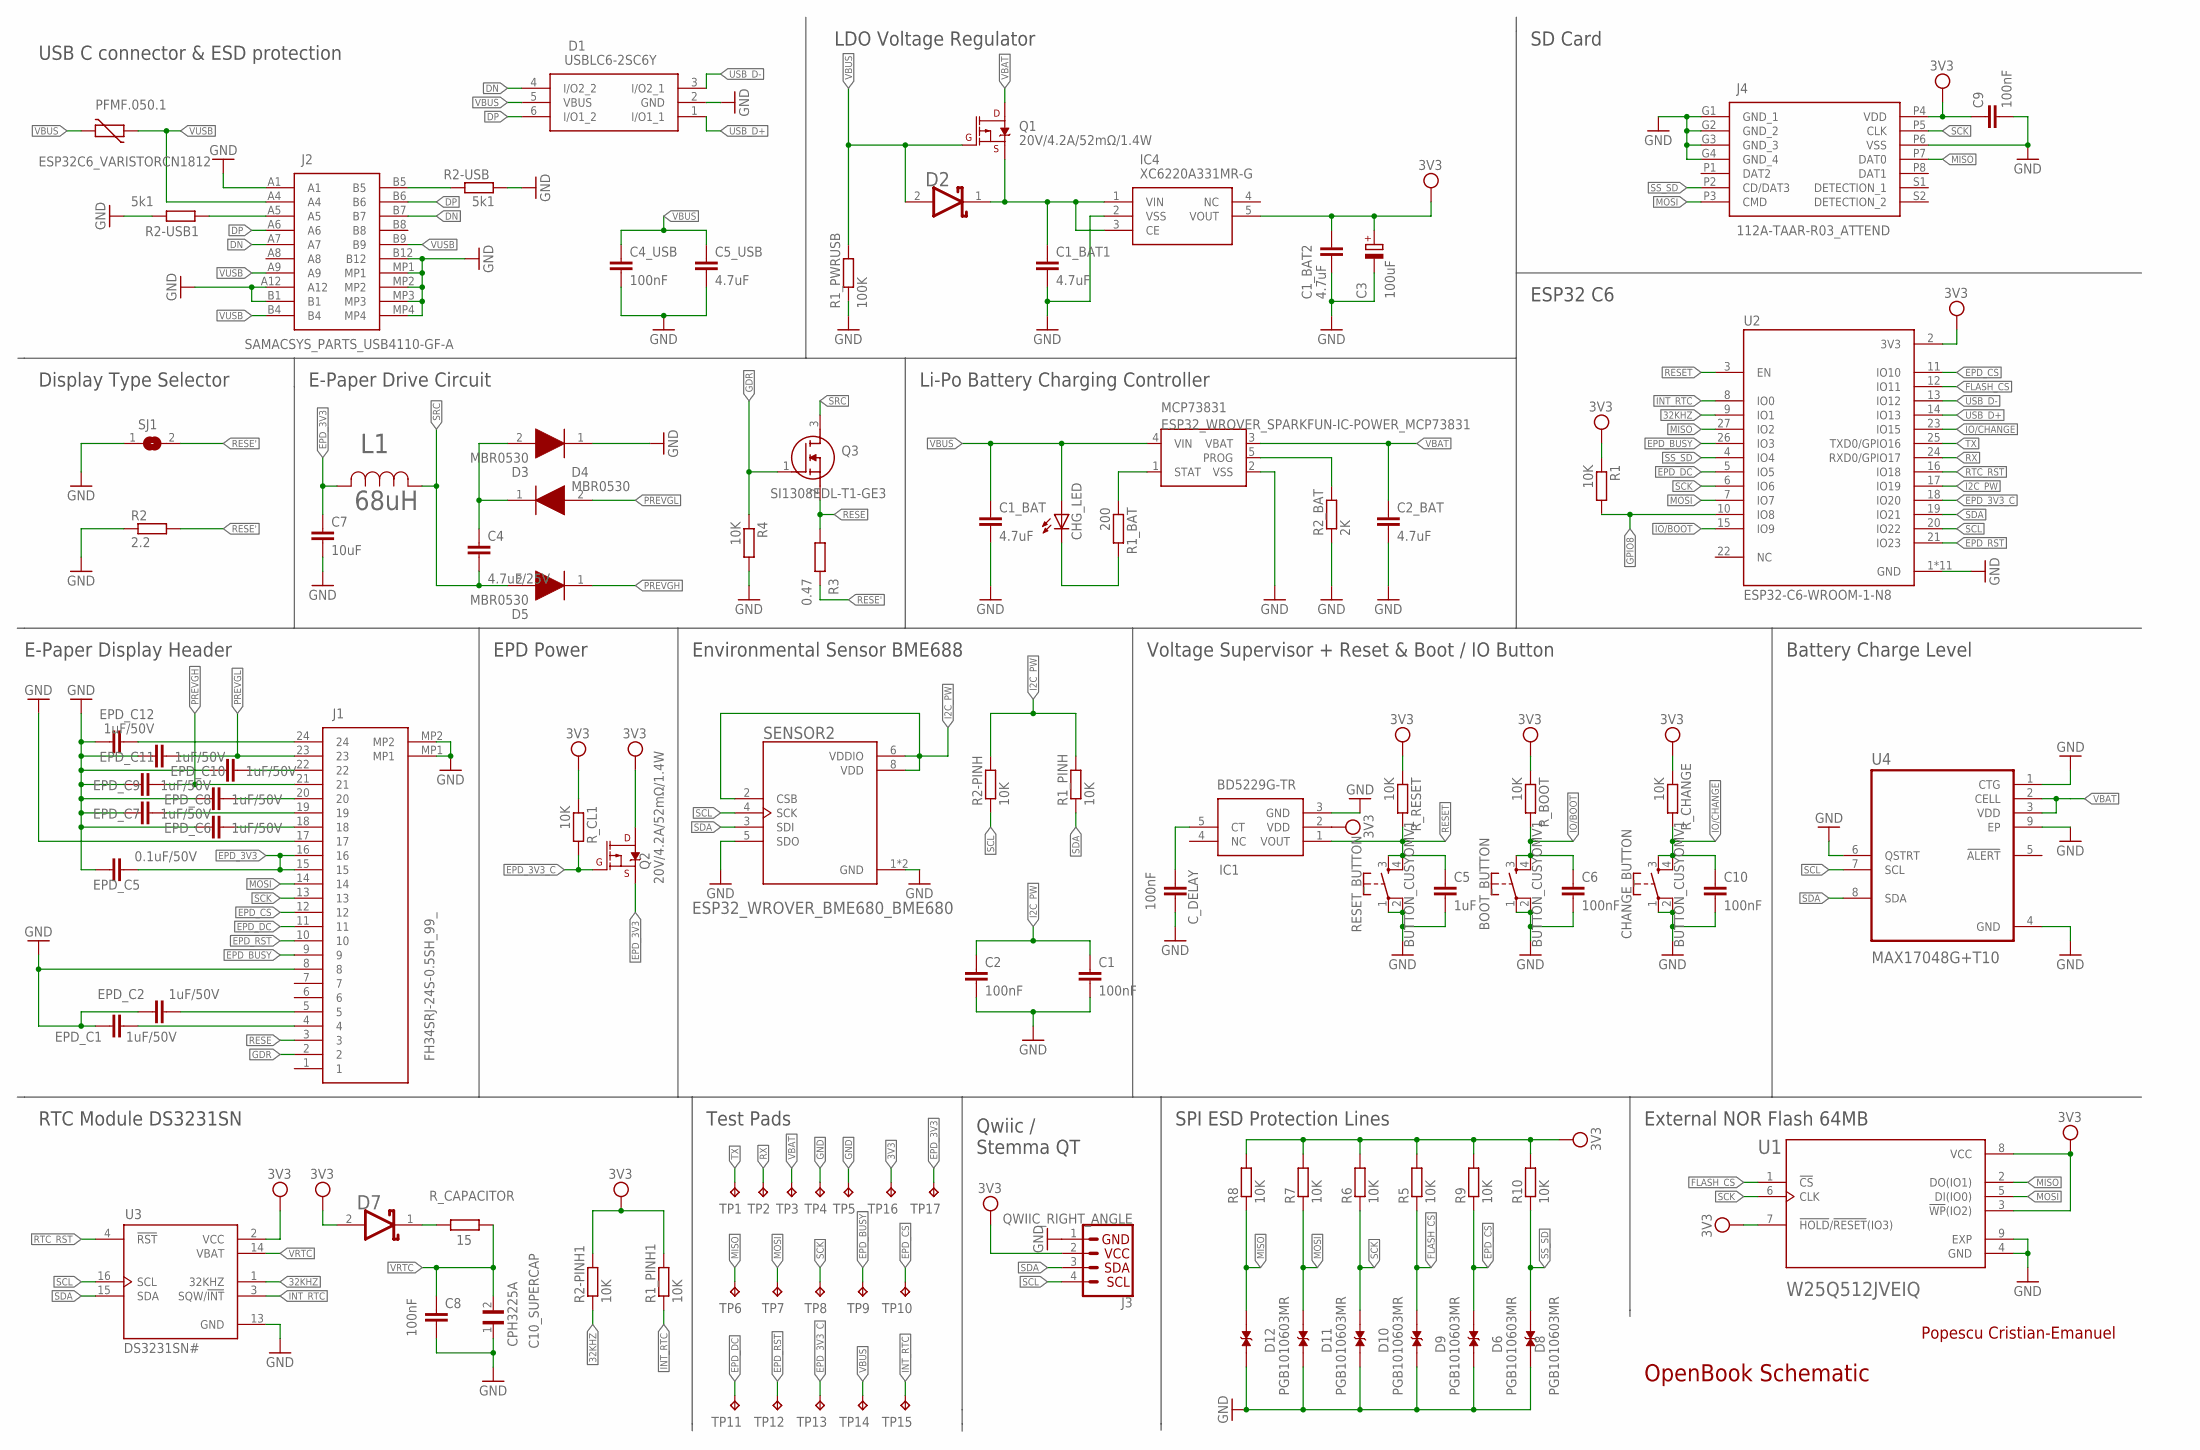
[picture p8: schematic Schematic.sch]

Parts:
BOOT_BUTTON: BUTTON_CUSYOMV1; MYBUTTON
C1, C2, C4_USB, C6, C8, C9, C10: 100nF; ESP32_WROVER_EAGLE-LTSPICE_C0402
C1_BAT, C1_BAT1, C1_BAT2, C2_BAT, C5_USB: 4.7uF; ESP32_WROVER_EAGLE-LTSPICE_C0402
C3: 100uF; RCL_CT3528
C4: 4.7uF/25V; ESP32_WROVER_EAGLE-LTSPICE_C0402
C5: 1uF; ESP32_WROVER_EAGLE-LTSPICE_C0402
C7: 10uF; ESP32_WROVER_EAGLE-LTSPICE_C0402
C10_SUPERCAP: CPH3225A; CAPCP3225X100N
CHANGE_BUTTON: BUTTON_CUSYOMV1; MYBUTTON
CHG_LED: ADAFRUIT_LEDCHIP-LED0603; ADAFRUIT_CHIP-LED0603
C_DELAY: 100nF; ESP32_WROVER_EAGLE-LTSPICE_C0402
D1: USBLC6-2SC6Y; SOT95P280X145-6N
D2, D7: ESP32_WROVER_AVX---SD0805S020S1R0_AVX_SD0805S020S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; ESP32_WROVER_AVX---SD0805S020S1R0_AVX_SD0805S020S1R0_0
D3, D4, D5: MBR0530; SOD3716X135N
D6, D8, D9, D10, D11, D12: PGB1010603MR; DIOC1608X36N
EPD_C1, EPD_C2, EPD_C6, EPD_C7, EPD_C8, EPD_C9, EPD_C10, EPD_C11, EPD_C12: 1uF/50V; ESP32_WROVER_EAGLE-LTSPICE_C0402
EPD_C5: 0.1uF/50V; ESP32_WROVER_EAGLE-LTSPICE_C0402
IC1: BD5229G-TR; SOT95P280X125-5N
IC4: XC6220A331MR-G; SOT95P280X120-5N
J1: FH34SRJ-24S-0.5SH_99_; FH34SRJ24S05SH99
J2: SAMACSYS_PARTS_USB4110-GF-A; SAMACSYS_PARTS_USB4110GFA
J3: QWIIC_RIGHT_ANGLE; JST04_1MM_RA
J4: 112A-TAAR-R03_ATTEND; 112ATAARR03ATTEND
L1: 68uH; IND_4828-WE-TPC_WRE
MCP73831: ESP32_WROVER_SPARKFUN-IC-POWER_MCP73831; ESP32_WROVER_SPARKFUN-IC-POWER_SOT23-5
PFMF.050.1: ESP32C6_VARISTORCN1812; ESP32C6_VARISTOR_CT/CN1812
Q1, Q2: 20V/4.2A/52mΩ/1.4W; ESP32_WROVER_SPARKFUN-DISCRETESEMI_SOT23-3
Q3: SI1308EDL-T1-GE3; SOT65P210X110-3N
R1, R1_PINH, R1_PINH1, R2-PINH, R2-PINH1, R4, R5, R6, R7, R8, R9, R10: 10K; ESP32_WROVER_EAGLE-LTSPICE_R0402
R1_BAT: 200; ESP32_WROVER_EAGLE-LTSPICE_R0402
R1_PWRUSB: 100K; ESP32_WROVER_EAGLE-LTSPICE_R0402
R2: 2.2; ESP32_WROVER_EAGLE-LTSPICE_R0402
R2-USB, R2-USB1: 5k1; ESP32_WROVER_EAGLE-LTSPICE_R0402
R2_BAT: 2K; ESP32_WROVER_EAGLE-LTSPICE_R0402
R3: 0.47; ESP32_WROVER_EAGLE-LTSPICE_R0402
RESET_BUTTON: BUTTON_CUSYOMV1; MYBUTTON
R_BOOT: 10K; ESP32_WROVER_EAGLE-LTSPICE_R0402
R_CAPACITOR: 15; ESP32_WROVER_EAGLE-LTSPICE_R0402
R_CHANGE: 10K; ESP32_WROVER_EAGLE-LTSPICE_R0402
R_CL1: 10K; ESP32_WROVER_EAGLE-LTSPICE_R0402
R_RESET: 10K; ESP32_WROVER_EAGLE-LTSPICE_R0402
SENSOR2: ESP32_WROVER_BME680_BME680; ESP32_WROVER_BME680_PSON80P300X300X100-8N
SJ1: SJ
TP1, TP2, TP3, TP4, TP5, TP6, TP7, TP8, TP9, TP10, TP11, TP12, TP13, TP14, TP15, TP16, TP17: TPTP20R; TP20R
U1: W25Q512JVEIQ; SON127P600X800X80-9N
U2: ESP32-C6-WROOM-1-N8; XCVR_ESP32-C6-WROOM-1-N8
U3: DS3231SN#; SOIC127P1032X265-16N
U4: MAX17048G+T10; SON50P200X200X80-9N

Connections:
3V3: C1_BAT2.1, C3.+, C9.1, D7.2 (ANODE), IC1.2 (VDD), IC4.5 (VOUT), J3.2, J4.P4 (VDD), Q2.3 (D), R1.1, R1_PINH1.2, R2-PINH1.2, R5.2, R6.2, R7.2, R8.2, R9.2, R10.2, R_BOOT.1, R_CHANGE.1, R_CL1.1, R_RESET.1, TP16.TP, U1.3 (!WP!(IO2)), U1.7 (!HOLD!/!RESET!(IO3)), U1.8 (VCC), U2.2 (3V3), U3.2 (VCC)
32KHZ: R2-PINH1.1, U2.9 (IO1), U3.1 (32KHZ)
DN: D1.4 (I/O2_2), J2.A7, J2.B7
DP: D1.6 (I/O1_2), J2.A6, J2.B6
EPD_3V3: C7.1, EPD_C5.1, J1.15, J1.16, L1.2, Q2.2 (S), TP17.TP
EPD_3V3_C: Q2.1 (G), R_CL1.2, TP13.TP, U2.18 (IO20)
EPD_BUSY: J1.9, TP9.TP, U2.26 (IO3)
EPD_CS: D6.2, J1.12, R9.1, TP10.TP, U2.11 (IO10)
EPD_DC: J1.11, TP11.TP, U2.5 (IO5)
EPD_RST: J1.10, TP12.TP, U2.21 (IO23)
FLASH_CS: D9.2, R5.1, U1.1 (!CS), U2.12 (IO11)
GDR: J1.2, Q3.1 (G), R4.1
GND: BOOT_BUTTON.1, BOOT_BUTTON.2, C1.2, C1_BAT.2, C1_BAT1.2, C1_BAT2.2, C2.2, C2_BAT.2, C3.-, C4_USB.2, C5.2, C5_USB.2, C6.2, C7.2, C8.2, C9.2, C10.2, C10_SUPERCAP.1, CHANGE_BUTTON.1, CHANGE_BUTTON.2, C_DELAY.2, D1.2 (GND), D3.1 (K), D6.1, D8.1, D9.1, D10.1, D11.1, D12.1, EPD_C1.2, EPD_C2.2, EPD_C5.2, EPD_C6.2, EPD_C7.2, EPD_C8.2, EPD_C9.2, EPD_C10.2, EPD_C11.2, EPD_C12.2, IC1.3 (GND), IC4.2 (VSS), J1.8, J1.17, J1.MP1, J1.MP2, J2.A1, J2.A12, J2.B1, J2.B12, J2.MP1, J2.MP2, J2.MP3, J2.MP4, J3.1, J4.G1 (GND_1), J4.G2 (GND_2), J4.G3 (GND_3), J4.G4 (GND_4), J4.P6 (VSS), MCP73831.2 (VSS), R1_PWRUSB.1, R2.1, R2-USB.2, R2-USB1.1, R2_BAT.1, R4.2, RESET_BUTTON.1, RESET_BUTTON.2, SENSOR2.1 (GND), SENSOR2.5 (SDO), SENSOR2.7 (GND), SJ1.1, TP4.TP, TP5.TP, U1.4 (GND), U1.9 (EXP), U2.1 (GND), U2.28 (GND), U2.29_1 (GND), U2.29_2 (GND), U2.29_3 (GND), U2.29_4 (GND), U2.29_5 (GND), U2.29_6 (GND), U2.29_7 (GND), U2.29_8 (GND), U2.29_9 (GND), U3.13 (GND), U4.1 (CTG), U4.4 (GND), U4.6 (QSTRT), U4.9 (EP)
GPIO8: R1.2, U2.10 (IO8)
I2C_PW: C1.1, C2.1, R1_PINH.2, R2-PINH.2, SENSOR2.2 (CSB), SENSOR2.6 (VDDIO), SENSOR2.8 (VDD), U2.17 (IO19)
INT_RTC: R1_PINH1.1, TP15.TP, U2.8 (IO0), U3.3 (SQW/!INT)
IO/BOOT: BOOT_BUTTON.3, BOOT_BUTTON.4, C6.1, R_BOOT.2, U2.15 (IO9)
IO/CHANGE: C10.1, CHANGE_BUTTON.3, CHANGE_BUTTON.4, R_CHANGE.2, U2.23 (IO15)
MISO: D12.2, J4.P7 (DAT0), R8.1, TP6.TP, U1.2 (DO(IO1)), U2.27 (IO2)
MOSI: D11.2, J1.14, J4.P3 (CMD), R7.1, TP7.TP, U1.5 (DI(IO0)), U2.7 (IO7)
unnamed: D7.1 (CATHODE), R_CAPACITOR.2
unnamed: C_DELAY.1, IC1.5 (CT)
unnamed: MCP73831.5 (PROG), R2_BAT.2
unnamed: C4.1, D3.2 (A), D4.1 (K)
unnamed: C1_BAT1.1, D2.1 (CATHODE), IC4.1 (VIN), IC4.3 (CE), Q1.2 (S)
unnamed: MCP73831.1 (STAT), R1_BAT.1
unnamed: CHG_LED.C, R1_BAT.2
unnamed: EPD_C1.1, J1.4
unnamed: EPD_C2.1, J1.5
unnamed: EPD_C6.1, J1.18
unnamed: EPD_C7.1, J1.19
unnamed: EPD_C8.1, J1.20
unnamed: EPD_C10.1, J1.22
unnamed: EPD_C12.1, J1.24
unnamed: J2.A5, R2-USB1.2
unnamed: J2.B5, R2-USB.1
PREVGH: D5.1 (K), EPD_C9.1, J1.21
PREVGL: D4.2 (A), EPD_C11.1, J1.23
RESE: J1.3, Q3.2 (S), R3.1
RESE': R2.2, R3.2, SJ1.2
RESET: C5.1, IC1.1 (VOUT), RESET_BUTTON.3, RESET_BUTTON.4, R_RESET.2, U2.3 (EN)
RTC_RST: U2.16 (IO18), U3.4 (!RST)
RX: TP2.TP, U2.24 (RXD0/GPIO17)
SCK: D10.2, J1.13, J4.P5 (CLK), R6.1, TP8.TP, U1.6 (CLK), U2.6 (IO6)
SCL: J3.4, R2-PINH.1, SENSOR2.4 (SCK), U2.20 (IO22), U3.16 (SCL), U4.7 (SCL)
SDA: J3.3, R1_PINH.1, SENSOR2.3 (SDI), U2.19 (IO21), U3.15 (SDA), U4.8 (SDA)
SRC: C4.2, D5.2 (A), L1.1, Q3.3 (D)
SS_SD: D8.2, J4.P2 (CD/DAT3), R10.1, U2.4 (IO4)
TX: TP1.TP, U2.25 (TXD0/GPIO16)
USB_D+: D1.1 (I/O1_1), U2.14 (IO13)
USB_D-: D1.3 (I/O2_1), U2.13 (IO12)
VBAT: C2_BAT.1, MCP73831.3 (VBAT), Q1.3 (D), TP3.TP, U4.2 (CELL), U4.3 (VDD)
VBUS: C1_BAT.1, C4_USB.1, C5_USB.1, CHG_LED.A, D1.5 (VBUS), D2.2 (ANODE), MCP73831.4 (VIN), PFMF.050.1.2, Q1.1 (G), R1_PWRUSB.2, TP14.TP
VRTC: C8.1, C10_SUPERCAP.2, R_CAPACITOR.1, U3.14 (VBAT)
VUSB: J2.A4, J2.A9, J2.B4, J2.B9, PFMF.050.1.1

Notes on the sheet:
USB C connector & ESD protection
LDO Voltage Regulator
Display Type Selector
E-Paper Drive Circuit
Li-Po Battery Charging Controller
ESP32 C6
SD Card
E-Paper Display Header
EPD Power
Environmental Sensor BME688
Voltage Supervisor + Reset & Boot / IO Button
Battery Charge Level
External NOR Flash 64MB
SPI ESD Protection Lines
Qwiic / Stemma QT
Test Pads
RTC Module DS3231SN
OpenBook Schematic
Popescu Cristian-Emanuel

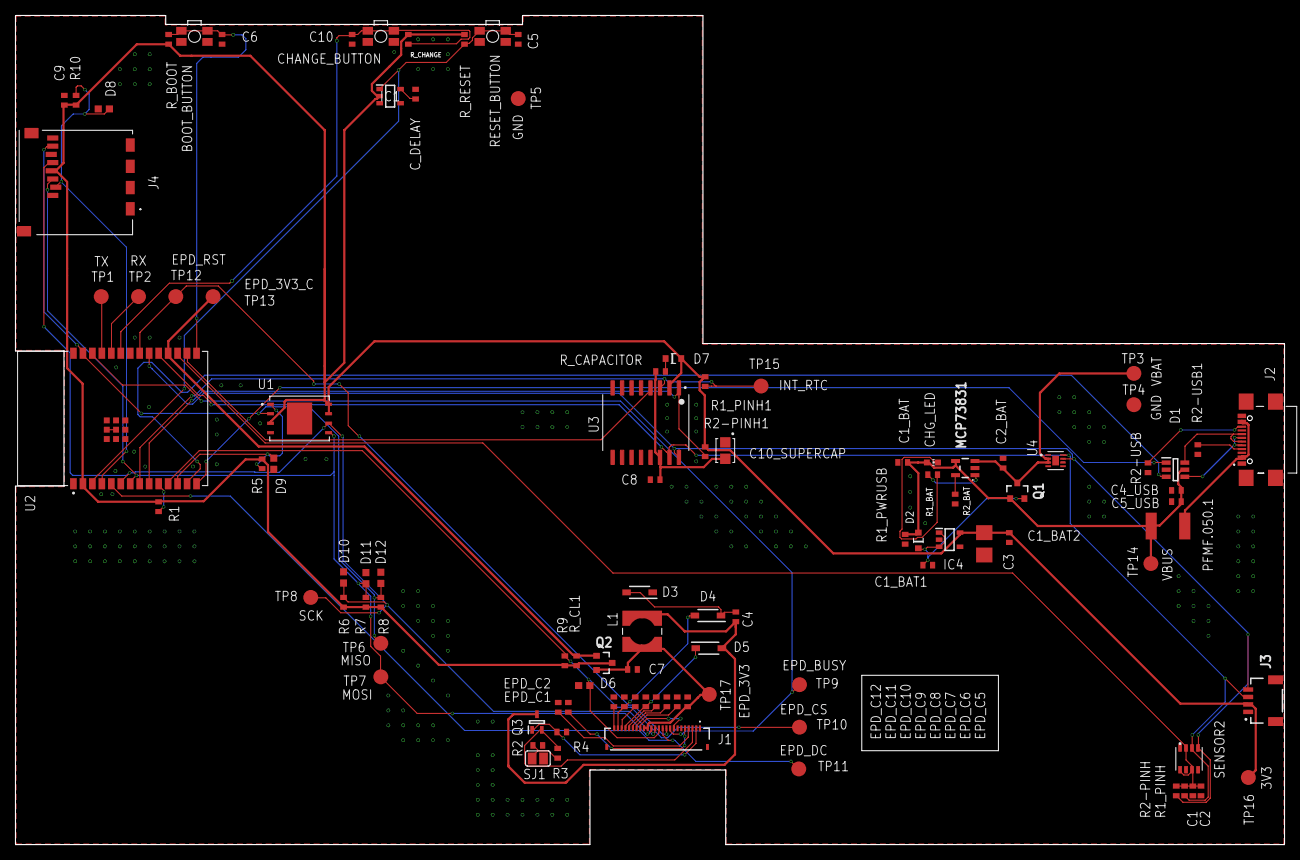
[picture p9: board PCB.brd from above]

Board: 2 copper layers, 170.2 x 111.2 mm, 103 parts (0 on the bottom side), 55 nets.

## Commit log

2025-04-06 Added final project
    [Bill of Material.csv, PCB.brd, Pick and Place.csv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]
2025-04-11 Fixed issues
    [Bill of Material.csv, PCB.brd, Pick and Place.csv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]

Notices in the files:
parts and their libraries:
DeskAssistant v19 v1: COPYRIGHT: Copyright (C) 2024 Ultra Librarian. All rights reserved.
